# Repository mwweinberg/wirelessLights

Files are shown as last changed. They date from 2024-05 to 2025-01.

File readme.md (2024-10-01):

# Wireless Lights

This is hardware and software to create remote controlled speaker notification lights.  There are two different lights, both of which are controlled from the same controller.  You can toggle which lights you are controlling with a switch on the controller itself.  You can also set the brightness of the lights.

animated gif of the lights in use

**[OSHWA CERTIFIED OPEN SOURCE HARDWARE!](https://certification.oshwa.org/us002664.html)**

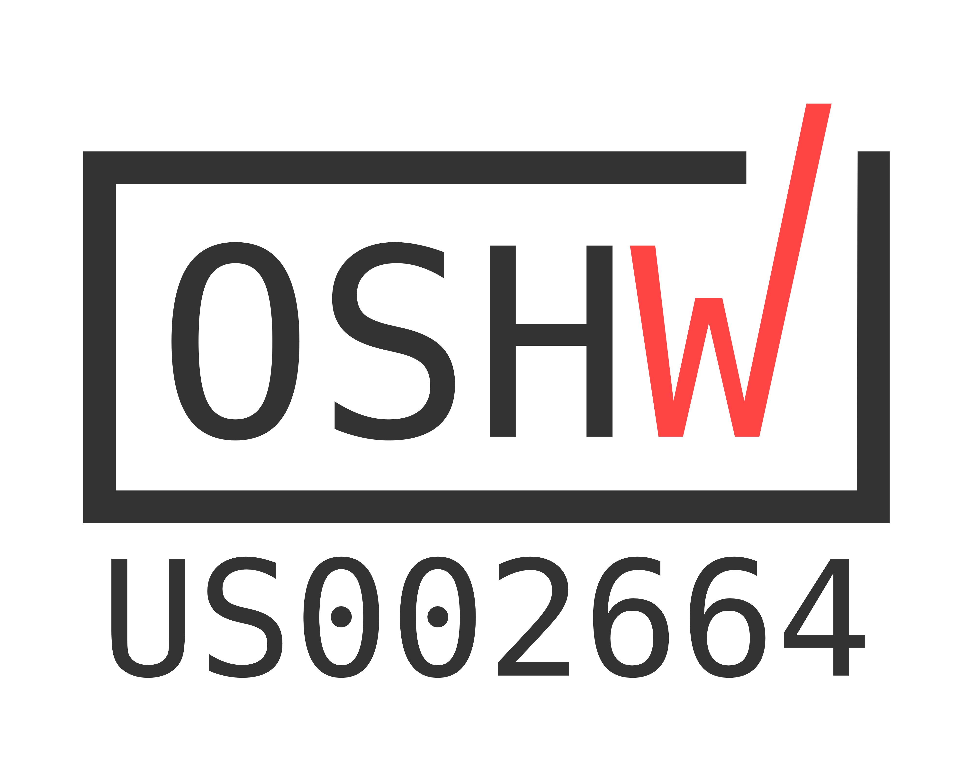
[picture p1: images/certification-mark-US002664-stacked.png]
certification mark UID US002664


## Controller buttons

### Top row (left to right, controls color of light)

Off, Red, Yellow, Green

### Bottom row (left to right)

Power, toggle which light you are controlling, brightness setting of controlled light 

### Wiring

Controller
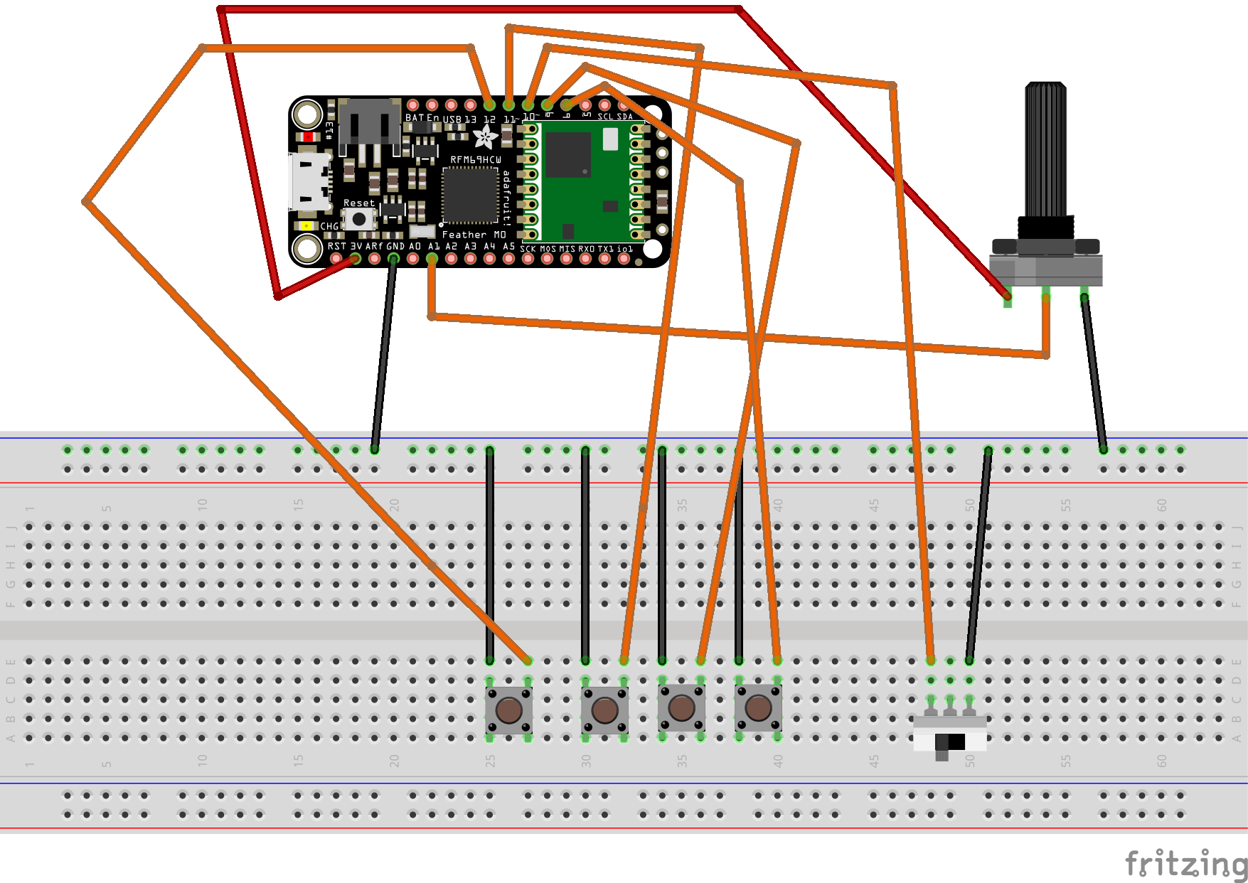
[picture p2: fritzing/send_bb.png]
fritzing wiring diagram


Light
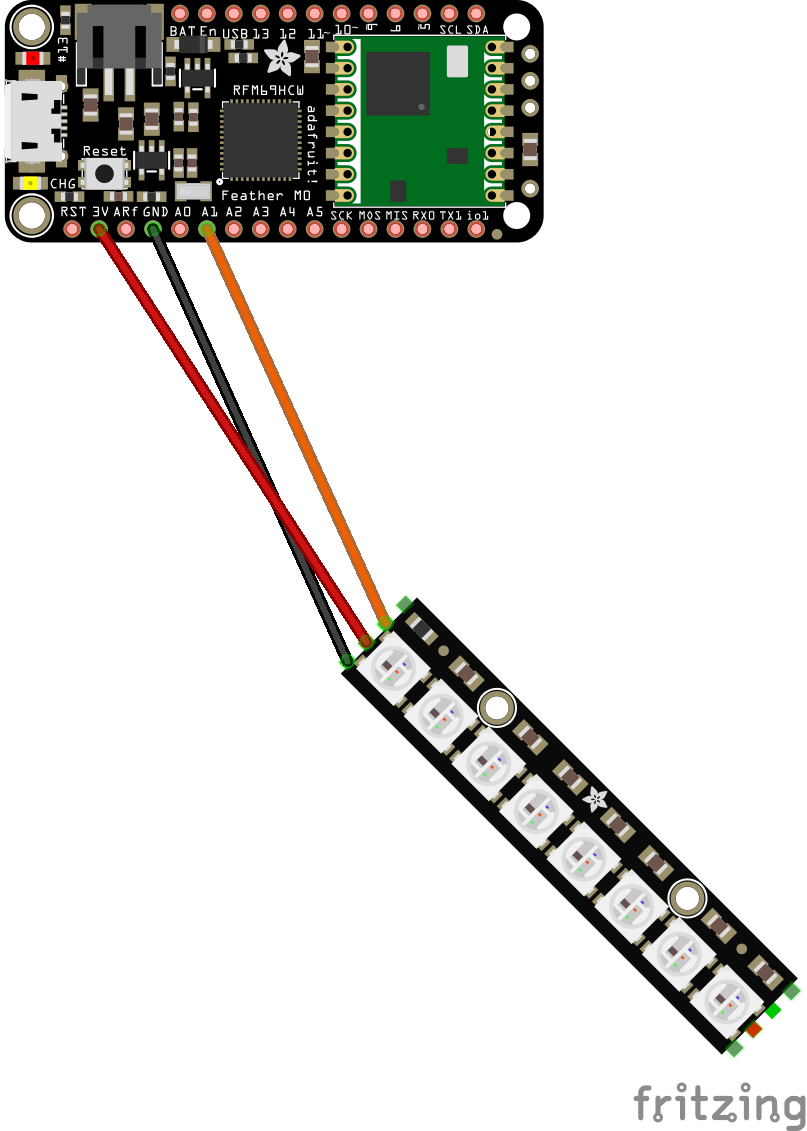
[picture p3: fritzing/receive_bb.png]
fritzing wiring diagram


# Building/editing

You will need to flash the feathers to use circuitpython:

#To flash circuit python onto a board on linux
The folder bossac-1.7.0 has both the flasher and the special version of circuitpython that works with the board. Open that folder in terminal and type 

./bossac -p /dev/ttyACM0 -e -w -v -R adafruit-circuitpython-feather_m0_rfm69-en_US-9.0.3.bin 

this command runs bossac (the flasher) targeted the board (/dev/ttyAMC0) and loads the version of circuitpython in the folder.  If for some reason you get an error about the board port, run ls /dev/ for a list of boards. There should be a ttyACM0, but maybe it is ttyACM1 or something? 

# Code 

send.py is the file for the transmitter
receive.py is the file for the primary receiver (when the transmitter is set to the first position)
receive_alt.py is the file for the second receiver (when the transmitter is set to the second position). The only difference between the two is the B numbers in lines 60-71

you also need to add the /lib files when you are setting up a new board

#/basic_board_exchange_scripts?

# TODO

- redesign controller to replace the 4 push buttons with a rotary switch + 1 "transmit" button.  These can be higher quality than the current buttons and this configuration will not take up any additional space on the controller
- reset dimmer switch so that turning it all the way down will not set brightness fully to 0. That is causing confusion.
- Add startup animation to lights to give a quick readout of the current battery level?

This folder has a simple send/recieve script pair that works for testing.  If everything breaks you can always roll back to them.

# Circuit diagrams 

in /fritzing

# License

HW: CERN-OHL-P-2.0; SW: MIT; DOC: CC-BY-4.0

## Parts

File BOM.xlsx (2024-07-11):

Item | Number | Unit Cost | Total Cost | Link | Notes
Adafruit Feather M0 RFM69HCW Packet Radio - 868 or 915 MHz - RadioFruit | 3 | $24.95 | $74.85 | https://www.adafruit.com/product/3176 | One for the transmitter and one for each reciever
NeoPixel Stick - 8 x 5050 RGBW LEDs - Natural White - ~4500K | 2 | $7.95 | $15.90 | https://www.adafruit.com/product/2868 | one for each reciever
Lithium Ion Polymer Battery - 3.7v 1200mAh | 3 | $9.95 | $29.85 | https://www.adafruit.com/product/258
battery extension cable | 3 | $1.95 | $5.85 | https://www.adafruit.com/product/1131 | for attaching battery to on-off switch
USB LiIon/LiPoly charger - v1.2 | 1 | $12.50 | $12.50 | https://www.adafruit.com/product/259
power switch | 3 | $0.55 | $1.65 | https://www.sparkfun.com/products/11138
push button | 4 | $1.05 | $4.20 | https://www.sparkfun.com/products/11996
potentiometer | 1 | $1.05 | $1.05 | https://www.sparkfun.com/products/9939
knob | 1 | $0.50 | $0.50 | https://www.adafruit.com/product/2047
toggle switch | 1 | $1.60 | $1.60 | https://www.sparkfun.com/products/11155
 |  |  | $147.95

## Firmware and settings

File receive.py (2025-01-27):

import board
import busio
import digitalio
import analogio
spi = busio.SPI(board.SCK, MOSI=board.MOSI, MISO=board.MISO)

cs = digitalio.DigitalInOut(board.RFM69_CS)
reset = digitalio.DigitalInOut(board.RFM69_RST)

import adafruit_rfm69
rfm69 = adafruit_rfm69.RFM69(spi, cs, reset, 915.0)

#for measuring power
vbat_voltage = analogio.AnalogIn(board.D9)

#for pixels
import time
import neopixel

pixel_pin = board.A1
num_pixels = 8
#use GRBW for the sticks, RGB for the circle
ORDER = neopixel.GRBW
pixels = neopixel.NeoPixel(pixel_pin, num_pixels, brightness=0.3, auto_write=False, pixel_order=ORDER)

RED = (255, 0, 0)
GREEN = (0,255,0)
BLUE = (0,0,255)
YELLOW = (255,255,0)
PURPLE = (0,255,255)
BLACK = (0,0,0)

#original startup
# color_state = BLUE
# pixels.fill(color_state)
# pixels[2] = RED
# pixels.show()

#get voltage
def get_voltage(pin):
    return (pin.value * 3.3 / 65536 * 2)
battery_voltage = get_voltage(vbat_voltage)
print("vbat voltage: ")
print(battery_voltage)

#illuminate lights at startup to show voltage
#according to the site below, "LiPoly batteries are 'maxed out' at 4.2V and stick around 3.7V for much of the battery life, then slowly sink down to 3.2V or so before the protection circuitry cuts it off. By measuring the voltage you can quickly tell when you're heading below 3.7V."
#https://learn.adafruit.com/adafruit-feather-m0-radio-with-rfm69-packet-radio/power-management

#move the red dot according to what the voltage is
pixels.fill(BLUE)
if battery_voltage > 4.1:
    pixels[7] = RED
elif battery_voltage > 4:
    pixels[6] = RED
elif battery_voltage > 3.9:
    pixels[5] = RED
elif battery_voltage > 3.7:
    pixels[4] = RED
elif battery_voltage > 3.6:
    pixels[3] = RED
elif battery_voltage > 3.3:
    pixels[2] = RED
elif battery_voltage > 3.1:
    pixels[1] = RED
else:
    pixels[0] = RED


pixels.show()


def update_lights(color, brightness_level):
    pixel.deinit()
    pixels = neopixel.NeoPixel(pixel_pin, num_pixels, brightness=brightness_level, auto_write=False, pixel_order=ORDER)

while True:


    packet = rfm69.receive()  # Wait for a packet to be received (up to 0.5 seconds)
    if packet is not None:
        packet_text = str(packet, 'ascii')
        print('Received: {0}'.format(packet_text))

        #parse the payload
        split_payload = packet_text.split(",")
        print(split_payload[0])
        payload_code = split_payload[0]
        brightness_value = split_payload[1]
        #not sure why you need to use eval to covert this into an int, but it works
        brightness_value_int = eval(brightness_value)
        print(brightness_value)
        

        #reset the brightness
        pixels.deinit()
        pixels = neopixel.NeoPixel(pixel_pin, num_pixels, brightness=brightness_value_int, auto_write=False, pixel_order=ORDER)

        if payload_code == 'B5':
            print('lights are off')
            color_state = BLACK
        if payload_code == 'B6':
            color_state = GREEN
            print('we have green lights')
        if payload_code == 'B7':
            color_state = YELLOW
            print('we have yellow lights')
        if payload_code == 'B8':
            color_state = RED
            print('we have red lights')
        pixels.fill(color_state)
        pixels.show()

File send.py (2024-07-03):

import board
import busio
import digitalio
import time
#radio
spi = busio.SPI(board.SCK, MOSI=board.MOSI, MISO=board.MISO)
cs = digitalio.DigitalInOut(board.RFM69_CS)
reset = digitalio.DigitalInOut(board.RFM69_RST)
import adafruit_rfm69
rfm69 = adafruit_rfm69.RFM69(spi, cs, reset, 915.0)
#buttons
from digitalio import DigitalInOut, Direction, Pull
#potentiometer
from analogio import AnalogIn
from adafruit_simplemath import map_range

#switch
switch = DigitalInOut(board.D10)
switch.direction = Direction.INPUT
switch.pull = Pull.UP

#buttons

button1 = DigitalInOut(board.D12)
button1.direction = Direction.INPUT
button1.pull = Pull.UP

button2 = DigitalInOut(board.D11)
button2.direction = Direction.INPUT
button2.pull = Pull.UP

button3 = DigitalInOut(board.D9)
button3.direction = Direction.INPUT
button3.pull = Pull.UP

button4 = DigitalInOut(board.D6)
button4.direction = Direction.INPUT
button4.pull = Pull.UP


#potentiometer
analog_in = AnalogIn(board.A1)
def get_voltage(pin):
    return (pin.value * 3.3) / 65536

#what gets sent to the other end
def payload(code, brightness):
    combined_values = code + "," + brightness
    print(combined_values)
    rfm69.send(combined_values)
    time.sleep(.5)


print("Started!")
while True:
    
    #potentiometer 
    #converts the mapped reading to a value between 0 and 1, limited to 2 decimal places
    #adjust the first two number arguments to reflect the max and min of the potentiometer reading
    #if this becomes problematic, you can always just hard code a value

    adjusted_potentiometer_reading = str(round(map_range(get_voltage(analog_in), 0, 3.2, 0, 1),2))
    #this line is just to calibrate the values above
    print(get_voltage(analog_in))
    print(adjusted_potentiometer_reading)

    if switch.value == True:
        print("true")
        if button1.value == True:
            print("off1")
        if button1.value == False:
            payload("B1", adjusted_potentiometer_reading)
            print("on1")
            # rfm69.send('B1 hello')
            # #cut this after testing -  just so you can see
            # time.sleep(.5)
        if button2.value == True:
            print("off2")
        if button2.value == False:
            payload("B2", adjusted_potentiometer_reading)
            print("on2")
            # rfm69.send('B2 hello')
            # #cut this after testing -  just so you can see
            # time.sleep(.5)
        if button3.value == False:
            payload("B3", adjusted_potentiometer_reading)
            print("on3")
        if button4.value == False:
            payload("B4", adjusted_potentiometer_reading)
            print("on4")

    elif switch.value == False:
        print("false")
        if button1.value == True:
            print("off3")
        if button1.value == False:
            payload("B5", adjusted_potentiometer_reading)
            # print("on3")
            # rfm69.send('B3 hello')
            # #cut this after testing -  just so you can see
            # time.sleep(.5)
        if button2.value == True:
            print("off5")
        if button2.value == False:
            payload("B6", adjusted_potentiometer_reading)
            # print("on4")
            # rfm69.send('B4 hello')
            # #cut this after testing -  just so you can see
            # time.sleep(.5)
        if button3.value == False:
            payload("B7", adjusted_potentiometer_reading)
            print("on7")
        if button4.value == False:
            payload("B8", adjusted_potentiometer_reading)
            print("on8")

    #else:
        #print("broken")
    #time.sleep(0.01)
    time.sleep(.5)

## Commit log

2024-04-07 added button to send
2024-04-07 moved the button send to the main folder & rolled back basic send
2024-04-07 added switch to send
2024-07-03 includes all four buttons
2024-07-03 mapped first four buttons to the correct colors
    [receive.py]
2024-07-11 updated to include all 4 buttons
    [send.fzz]
2025-01-27 added battery indicator to recieve startup
